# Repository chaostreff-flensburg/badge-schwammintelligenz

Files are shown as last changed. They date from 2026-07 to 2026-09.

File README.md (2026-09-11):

# badge-schwammintelligenz

## Ideensammlung
- PCB mit Gehirn-Form und Schwamm-Farbe
  - gelber Lötstopplack
  - nacktes FR4 als Kontrastfarbe für Porösität des Schwammes
  - Konturlinien in schwarzem oder weißem Bestückungsdruck
- viele sehr kleine LEDs auf der Vorderseite
  - blitzen auf, um Neuronen zu mimen
  - mit [Charlieplexing](https://en.wikipedia.org/wiki/Charlieplexing#Origin) kann man 110 LEDs mit nur 11 Pins einzeln ansteuern
    - (`nLedsMax = nGpio * (nGpio - 1)`)
    - [Beispielcode für Charlieplexing](https://goodarduinocode.com/guides/charlieplexing) -> Zeilenweise ansteuern
  - [XINGLIGHT XL0201UWC](https://jlcpcb.com/partdetail/XINGLIGHT-XL0201UWC/C965789) wäre z.B. nur 0,7 mm * 0,4 mm groß (Pads komplett unter dem Package) und kostet nur 0,0326 USD / St. bei 5000 St. Abnahme
- Kompatibilität zu Mesh-Cat-Ears?
  - [Rudelblinken](https://github.com/zebreus/rudelblinken)
  - Die laufen mit BLE auf einem ESP32-C3
  - Wir könnten denselben Controller nutzen, um mit den Katzenohren meshen zu können
- ein Taster auf der Rückseite, um einen Puls auszulösen
  - erstmal an den eigenen LEDs
  - langfristig sonst auch auf Gehirnen in der Nähe
  - evtl. jeder Mesh-Teilnehmer eine eigene LED?
  - 3-4 Taster (Soft touch) (Typ [Alps SKPM](https://tech.alpsalpine.com/e/products/detail/SKPMANE010/)?)

## Implementierung der Farben

Die Platine wird mit **gelbem Lötstopplack** und **weißem Bestückungsdruck** gefertigt.

Kupfer auf der Rückseite minimal halten und wo möglich unter dem Kupfer der Oberseite verlegen.

Der Entwurf sieht folgendermaßen aus:

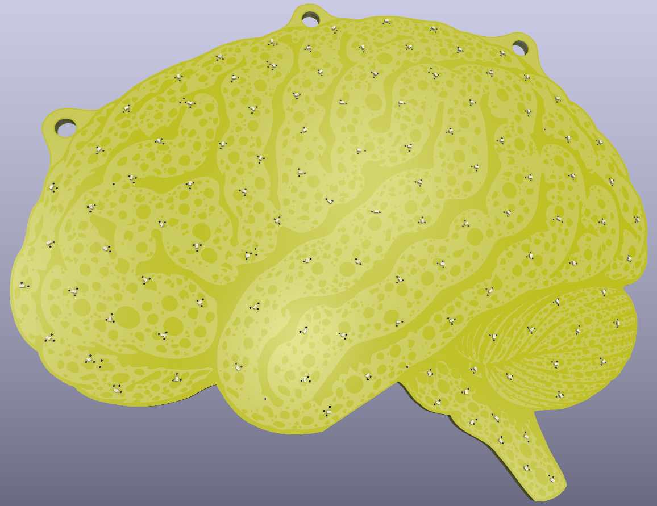
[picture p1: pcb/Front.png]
von vorne


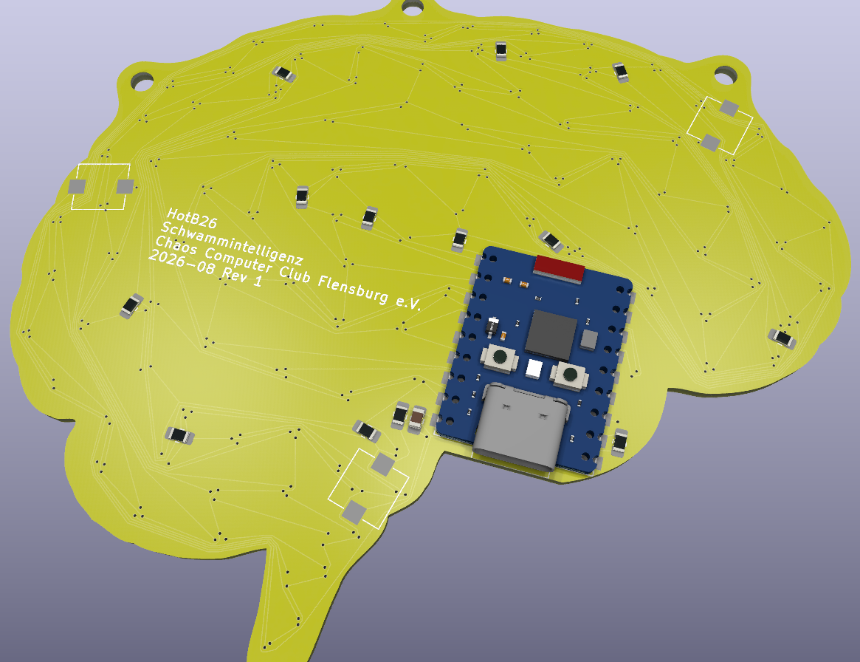
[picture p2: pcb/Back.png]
von hinten


### Farbaufbau

| Farbe | Objekte | Beteiligte Lagen | Notizen |
| --- | --- | --- | --- |
| weiß | ??? | F.Silkscreen | Bestückungsdruck (muss auf Lötstopplack liegen) |
| silber | ??? | F.Cu, F.Mask | freies Kupfer mit HASL Finish |
| hellergelb | Schwammoberfläche | F.Mask | blankes FR4 (kein Kupfer auf der Rückseite) - ca. `e9d645ff` |
| hellgelb | Vertiefung flach | none | Lötstopplack auf FR4 (kein Kupfer auf der Rückseite) - ca. `f6c50eff` |
| dunkelgelb | Vertiefung tief | F.Cu | Lötstopplack auf Kupfer - ca. `e8b203ff` |
| grüngelb | --- | F.Cu, F.Mask | blankes FR4 mit Kupfer auf der Rückseite |

### Lagenaufbau

| Lage | Objekte |
| --- | --- |
| F.Cu | union( silber, dunkelgelb ) |
| F.Mask | invert( union( weiß, hellgelb, dunkelgelb ) ) |
| F.Silkscreen | weiß |

## BOM

Die folgenden Preise beziehen sich auf ein einzelnes Badge wenn wir Material für 50 Stück kaufen.

- JLCPCB Preis vom 2026-06-15
  - PCB ca. 100 mm x 100 mm
  - Silkscreen gleb
  - 1,6 mm dick
  - LeadFree HASL
  - je 110 St. XINGLIGHT XL-0201UWC (LCSC C965789) von JLCPCB auf der Vorderseite bestückt
  - 258,80 € (Material und Produktion) + 48,03 € (Versand EuroPacket) = 306,83 €
  - Es ist mit 2 Wochen Lieferzeit zu rechnen, wenn es keine Rücksprachen braucht

| Anzahl | Preis | Bezeichnung |
| --- | --- | --- |
| 1 | 6,14 € | PCB mit LEDs (Stand 2026-06-15 von JLCPCB teilbestückt) |
| 1 | ca. 4 € | ESP32-C3 |
| ? | ??? | ??? |

## Firmware

Liegt in `firmware/` und läuft auf dem Waveshare ESP32-C3-Zero.

**Für alle, die einfach ein Badge haben:** Auf https://schwammhirn.c3fl.de/ gibt es alles in
einer Seite. Badge per USB anstecken, „Firmware flashen“ klicken, Port wählen. Danach per
Bluetooth verbinden und steuern. Keine Installation nötig, Chrome oder Edge am Desktop reicht
(zum Steuern auch Chrome auf Android, auf dem iPhone der Browser „Bluefy“).

**Zum Mitentwickeln:** Bauen wahlweise mit der Arduino IDE (Board „Waveshare ESP32-C3-Zero“,
Bibliothek NimBLE-Arduino 2.x) oder mit PlatformIO im Repo-Root: `pio run -t upload`.

- `firmware/led_map.h` wird von `tools/gen_led_map.py` aus `pcb/pcb.kicad_pcb` erzeugt
  (Pin-Paar, Position und Hirnareal jeder LED, die Areale aus den Beschriftungen auf
  Cmts.User). Nach Layoutänderungen neu ausführen, das Skript schreibt auch `web/led_map.js`.
- Ein Timer-Interrupt scannt die Charlieplex-Matrix mit 4 Bit Helligkeit, `loop()`
  rendert Animationen in einen Framebuffer.
- Taster: kurz drücken löst eine Welle aus (auch auf Badges in Reichweite), lang drücken
  wechselt den Modus (Neuronen, Wellen, Cortex, Suche, Laufschrift, Löt-Test). Im Löt-Test startet kurz
  drücken den Durchlauf von vorne. Alle drei Taster liegen auf demselben Eingang.
- Sync: Badges senden Modus, Tempo, Helligkeit, Schriftlayout und Phase per BLE-Advertising.
  Die höchste Änderungsgeneration gewinnt, bei Gleichstand die kleinere ID. Kein
  Verbindungsaufbau nötig. Der Text selbst wird nicht übertragen.
- BLE-Anzeigename ist standardmäßig `Schwammhirn-<ID>` aus der Bluetooth-MAC, änderbar.
  Die Web-Seite findet Badges über die Herstellerkennung im Werbepaket, unabhängig vom Namen.

### Modi

| Modus | Kommando | Was passiert |
| --- | --- | --- |
| Neuronen | `mode neurons` | zufällige Blitze, die ausklingen (Standard) |
| Wellen | `mode pulse` | Ringe laufen von einem zufälligen Punkt nach außen |
| Suche | `mode radar` | Radarstrahl kreist um die Mitte. Je Badge in Reichweite ein Herzschlag-Ring von innen nach außen, schneller und heller je näher (Signalstärke der Werbepakete, −95 dBm weit bis −65 dBm direkt daneben) |
| Cortex | `mode cortex` | ein Hirnareal (Frontal-, Parietal-, Temporal-, Okzipitallappen, Kleinhirn, Stammhirn, aus den Beschriftungen im PCB) blitzt auf, schwächere Wellen laufen von dort in den Rest |
| Laufschrift | `mode text` | Text läuft durch, Größe und Abstand oben einstellbar |
| Löt-Test | `mode test` | füllt jede Zeile LED für LED, dann dunkel, nächste Zeile; danach dasselbe spaltenweise. Jede neue LED wird gemeldet. Fehlt eine LED, ist es die Lötstelle; fehlt eine Zeile oder Spalte, der GPIO oder sein 10-Ω-Widerstand. Wird nicht synchronisiert und nicht gespeichert. |
| Malen | `mode remote` | zeigt ein Rohbild, das per `frame` gesendet wurde (Web-Seite: LEDs antippen) |

### Kommandos (Serial und BLE)

Dieselben Textkommandos gehen über Serial (115200 Baud, USB) und über BLE. BLE nutzt den
Nordic-UART-Service (Schreiben auf `6E400002-…`, Antworten als Notify auf `6E400003-…`),
jede BLE-Terminal-App funktioniert also, zum Beispiel „Serial Bluetooth Terminal“ auf Android.
Eine Zeile pro Kommando, Antwort beginnt mit `ok` oder `err`.

| Kommando | Bedeutung |
| --- | --- |
| `mode <name>` oder `mode <0-6>` | Modus wählen: `neurons`, `pulse`, `cortex`, `radar`, `text`, `test`, `remote` |
| `text <Text>` | Laufschrift setzen, max. 63 Zeichen, Umlaute werden ersetzt, schaltet auf Laufschrift |
| `tsize <1-5>` | Schriftgröße (Leinwand-Pixel pro Font-Pixel), Standard 3 |
| `ty <0-30>` | Abstand der Schrift vom oberen Rand, Standard 6 |
| `speed <0-100>` | Tempo aller Animationen, Standard 4 |
| `bright <1-15>` | Helligkeit, Standard 15 |
| `pulse` oder `pulse <LED 0-109>` | Welle auslösen, auch auf Badges in Reichweite. Im Löt-Test: Durchlauf neu starten |
| `frame <220 Hex-Zeichen>` | Rohbild, ein Byte Helligkeit pro LED in D-Reihenfolge, schaltet auf Malen |
| `name <Name>` | BLE-Anzeigename, max. 20 Zeichen, leer = Standard `Schwammhirn-<ID>` |
| `sync on` / `sync off` | Einstellungen von Badges in der Nähe übernehmen oder ignorieren |
| `mirror on` / `mirror off` | Framebuffer etwa 10-mal pro Sekunde als `F<220 Hex>` per BLE-Notify streamen (Live-Bild der Web-Seite) |
| `peers` | Badges in Reichweite mit ID, Signalstärke, Nähe und Alter des letzten Pakets auflisten |
| `status` | Zustand ausgeben: Modus, Tempo, Helligkeit, Schriftlayout, Text, Sync, Generation, ID, Badges in Reichweite, Name |

Modus, Tempo, Helligkeit, Text, Schriftlayout und Name bleiben über Neustarts erhalten.

### Web-Steuerung

Unter https://schwammhirn.c3fl.de/ oder lokal aus `web/index.html`. „Mit Badge verbinden“
drücken, dann Modi, Text, Regler und Umbenennen. Zeigt live das Bild des Badges, im Modus
„Malen“ lassen sich LEDs antippen. Ohne Verbindung läuft dieselbe Animation als Simulation
1:1 auf der Platinenkontur, so lässt sich zum Beispiel Laufschrift vorab beurteilen.
Web Bluetooth braucht HTTPS oder localhost, deshalb funktioniert Verbinden aus dem
Dateisystem nur in Chrome, das `file://` als sicher behandelt.

Firmware flashen ohne Toolchain: Button „Firmware flashen“ (ESP Web Tools, Chrome/Edge am
Desktop). Die Binaries liegen in `web/flash/`, die Seite zeigt den Commit-Hash der Version.
Nach einer Firmware-Änderung: `pio run`, Code committen, dann `tools/export_firmware.sh` und
die Binaries als eigenen Commit nachschieben.

Deployment: Das `Dockerfile` im Repo-Root liefert `web/` per nginx aus. In Coolify eine
Ressource vom Typ „Public Repository“ mit Build Pack „Dockerfile“ anlegen, Port 80, Domain
eintragen. HTTPS macht Coolify per Let's Encrypt. Nach jedem Merge einmal redeployen.

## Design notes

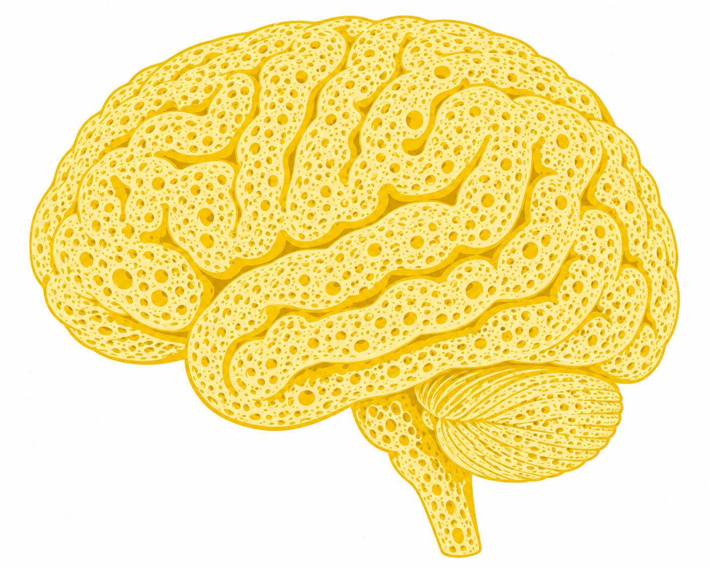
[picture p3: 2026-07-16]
Schwammhirn_original.png

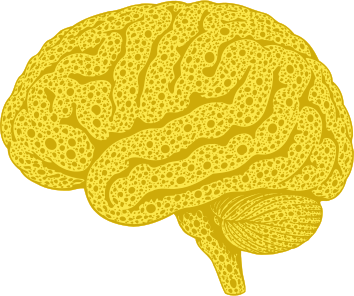
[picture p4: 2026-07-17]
Schwammhirn_3stufig.png

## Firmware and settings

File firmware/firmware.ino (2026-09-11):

// Firmware für das Schwammhirn-Badge: ESP32-C3-Zero auf der Platine aus diesem Repo.
//
// Aufbau:
//   * Ein Timer-Interrupt scannt die 110 Charlieplex-LEDs mit 4 Bit Helligkeit.
//   * loop() rendert Animationen in einen 110-Byte-Framebuffer (0..255 pro LED).
//     Flächige Animationen zeichnen auf eine kleine virtuelle Leinwand, aus der
//     jede LED an ihrer Position auf der Platine abtastet (siehe led_map.h).
//   * Kommandos kommen per Serial oder BLE (Nordic-UART-Service), gleiche Syntax.
//   * Badges in Reichweite synchronisieren Modus, Tempo, Helligkeit und Phase
//     über BLE-Advertising. Ein Tastendruck löst eine Welle auf allen aus.
//
// Kommandos (Serial 115200 oder BLE RX, eine Zeile pro Kommando):
//   mode <0-6|neurons|pulse|cortex|radar|text|test|remote>   Modus wählen
//                      cortex: ein Hirnareal blitzt auf, schwächere Wellen laufen in den Rest
//                      radar: Suchmodus, Radarstrahl kreist, je Badge in Reichweite ein Herzschlag-Ring,
//                             schneller und heller je näher (Signalstärke der Werbepakete)
//                      test: Löt-Test, füllt jede Zeile LED für LED, dann aus, nächste Zeile;
//                      danach dasselbe mit den Spalten. So läuft jeder GPIO als Kathode und Anode.
//   text <Text>        Laufschrift setzen (ASCII, Umlaute werden ersetzt)
//   name <Name>        BLE-Anzeigename (max. 20 Zeichen), Standard Schwammhirn-<ID>
//   tsize <1-5>        Schriftgröße der Laufschrift (Leinwand-Pixel pro Font-Pixel)
//   ty <0-30>          Abstand der Laufschrift vom oberen Rand in Leinwand-Pixeln
//   speed <0-100>      Tempo
//   bright <1-15>      Helligkeit
//   pulse              Welle auslösen (auch auf Badges in Reichweite); im Löt-Test: Test neu starten
//   frame <220 Hex>    Rohbild, ein Byte pro LED, schaltet auf Modus remote
//   sync <on|off>      Sync mit anderen Badges
//   mirror <on|off>    Framebuffer als "F<hex>" per BLE-Notify streamen (~10 Hz)
//   status             Zustand ausgeben
//   peers              Badges in Reichweite mit Signalstärke auflisten

#include <Arduino.h>
#include <NimBLEDevice.h>
#include <Preferences.h>
#include <soc/gpio_reg.h>
#include <driver/gpio.h>
#include <esp_mac.h>
#include <esp_random.h>
#include <math.h>

#include "led_map.h"
#include "font5x7.h"

constexpr int MATRIX_PINS[PIN_COUNT] = {5, 6, 4, 7, 3, 8, 2, 9, 1, 0, 20}; // Col0..Col10
constexpr int BUTTON_PIN = 21; // alle drei Taster parallel, aktiv HIGH

// WS2812-Status-LED des C3-Zero an GPIO10. Bewusst nicht RGB_BUILTIN: die generische
// C3-Variante legt das auf GPIO8, und das ist Zeile 5 der LED-Matrix.
constexpr int STATUS_LED = SOC_GPIO_PIN_COUNT + 10;

// Typen stehen vor der ersten Funktion, weil der Arduino-Präprozessor dort seine Prototypen einfügt.
enum Mode : uint8_t { NEURONS, PULSE, CORTEX, RADAR, TEXT, TEST, REMOTE, MODE_COUNT }; // Taster rotiert bis TEST; ab TEST kein Sync, kein Speichern

struct __attribute__((packed)) SyncPacket
{
  uint8_t company[2]; // 0xFFFF = Testkennung
  uint8_t magic[2];   // 'S','H'
  uint8_t version;
  uint16_t id;
  uint16_t generation;
  uint8_t mode, speed, brightness;
  uint16_t phase;     // animTime() & 0xFFFF
  uint8_t pulseSeq, pulseOrigin;
  uint8_t textScale, textY;
};

// Badges in Reichweite, gesehen über ihre Sync-Pakete
struct Peer { uint16_t id; uint8_t pulseSeq; uint32_t lastSeen; int8_t rssi; };
Peer peers[16];
constexpr uint32_t PEER_TIMEOUT_MS = 10000;
inline bool peerActive(const Peer& p) { return p.id && millis() - p.lastSeen < PEER_TIMEOUT_MS; }
// Nähe 0..1 aus der Signalstärke. Gemessen: nebeneinander auf dem Tisch -75 dBm, anderer Raum -97 dBm.
float peerNearness(const Peer& p) { return constrain((p.rssi + 95) / 30.0f, 0.0f, 1.0f); }

constexpr bool pinInMatrix(int gpio)
{
  for (int p : MATRIX_PINS)
    if (p == gpio) return true;
  return false;
}
static_assert(!pinInMatrix(STATUS_LED - SOC_GPIO_PIN_COUNT), "Status-LED liegt auf einem Matrix-Pin");
static_assert(!pinInMatrix(BUTTON_PIN), "Taster liegt auf einem Matrix-Pin");

// ---------------------------------------------------------------------------
// Charlieplex-Scan (Timer-ISR). 4 Bitebenen pro Spalte, Bitebene b dauert 2^b Ticks.
// ---------------------------------------------------------------------------
constexpr int PLANES = 4;
constexpr uint32_t TICK_US = 30; // 11 Spalten * 15 Ticks * 30 us = 5 ms => ~200 Hz Bildwiederholung

uint32_t pinMask[PIN_COUNT];
uint32_t allPinsMask = 0;
volatile uint32_t rowMask[2][PIN_COUNT][PLANES]; // [Puffer][Spalte][Bitebene] -> Kathoden-Pins
volatile uint8_t activeBuf = 0;
hw_timer_t* scanTimer = nullptr;

void ARDUINO_ISR_ATTR onScanTick()
{
  static uint8_t col = 0, plane = 0, remaining = 1;
  if (--remaining) return;

  REG_WRITE(GPIO_ENABLE_W1TC_REG, allPinsMask); // alles hochohmig
  uint32_t rows = rowMask[activeBuf][col][plane];
  if (rows)
  {
    REG_WRITE(GPIO_OUT_W1TS_REG, pinMask[col]);
    REG_WRITE(GPIO_OUT_W1TC_REG, rows);
    REG_WRITE(GPIO_ENABLE_W1TS_REG, pinMask[col] | rows);
  }

  remaining = 1 << plane;
  if (++plane == PLANES)
  {
    plane = 0;
    if (++col == PIN_COUNT) col = 0;
  }
}

// ---------------------------------------------------------------------------
// Zustand
// ---------------------------------------------------------------------------
const char* const MODE_NAMES[MODE_COUNT] = {"neurons", "pulse", "cortex", "radar", "text", "test", "remote"};

struct State
{
  Mode mode = NEURONS;
  uint8_t speed = 4;      // 0..100
  uint8_t brightness = 15; // 1..15
  char text[64] = "SCHWAMMHIRN";
  char name[21] = "";     // BLE-Anzeigename, leer = Standard aus myId
  uint8_t textScale = 3;  // 1..5
  uint8_t textY = 6;      // 0..30
  bool syncEnabled = true;
  bool mirror = false;
} st;

uint8_t fb[LED_COUNT];      // Framebuffer 0..255
uint32_t epoch = 0;         // Animationszeit t = millis() - epoch, per Sync verschiebbar
uint16_t generation = 0;    // Lamport-Zähler für den Sync: höchste Generation gewinnt
uint16_t myId;
uint8_t pulseSeq = 0;       // zählt eigene Pulse, damit Nachbarn neue erkennen
uint8_t pulseOrigin = 0;
uint32_t dirtySince = 0;    // Zeitpunkt der letzten Änderung, für verzögertes Speichern
bool advertDirty = true;

Preferences prefs;

inline uint32_t animTime() { return millis() - epoch; }

// ---------------------------------------------------------------------------
// Framebuffer -> Scan-Puffer
// ---------------------------------------------------------------------------
void show()
{
  uint8_t next = activeBuf ^ 1;
  for (int c = 0; c < PIN_COUNT; ++c)
    for (int p = 0; p < PLANES; ++p) rowMask[next][c][p] = 0;

  for (int i = 0; i < LED_COUNT; ++i)
  {
    uint8_t v = (fb[i] * (st.brightness + 1)) >> 8; // 0..brightness
    for (int p = 0; p < PLANES; ++p)
      if (v & (1 << p)) rowMask[next][LEDS[i].col][p] |= pinMask[LEDS[i].row];
  }
  activeBuf = next;
}

// ---------------------------------------------------------------------------
// Virtuelle Leinwand, ca. 2 mm pro Pixel
// ---------------------------------------------------------------------------
constexpr int CW = 48;
constexpr int CH = 40;
uint8_t canvas[CW * CH];

void canvasClear() { memset(canvas, 0, sizeof(canvas)); }

inline void canvasSet(int x, int y, uint8_t v)
{
  if (x < 0 || y < 0 || x >= CW || y >= CH) return;
  uint8_t& px = canvas[y * CW + x];
  if (v > px) px = v;
}


// Jede LED nimmt das Maximum ihrer Nachbarschaft (radius 1 = 3x3), damit dünne Linien nicht durchfallen.
void sampleCanvas(int radius)
{
  for (int i = 0; i < LED_COUNT; ++i)
  {
    int cx = LEDS[i].x * CW / 256, cy = LEDS[i].y * CH / 256;
    uint8_t m = 0;
    for (int dy = -radius; dy <= radius; ++dy)
      for (int dx = -radius; dx <= radius; ++dx)
      {
        int x = cx + dx, y = cy + dy;
        if (x >= 0 && y >= 0 && x < CW && y < CH) m = max(m, canvas[y * CW + x]);
      }
    fb[i] = m;
  }
}

// ---------------------------------------------------------------------------
// Wellen (Overlay in jedem Modus)
// ---------------------------------------------------------------------------
struct Wave { uint32_t start; uint8_t origin; bool active; };
Wave waves[4];

void triggerWave(uint8_t origin)
{
  for (Wave& w : waves)
    if (!w.active)
    {
      w = {millis(), origin, true};
      return;
    }
  waves[0] = {millis(), origin, true};
}

void renderWaves()
{
  for (Wave& w : waves)
  {
    if (!w.active) continue;
    uint32_t age = millis() - w.start;
    if (age > 1800) { w.active = false; continue; }
    float r = age * 0.25f;                     // Radius in LED-Koordinaten (0..255), ~1 Sekunde bis zum Rand
    float fade = 1.0f - age / 1800.0f;
    int ox = LEDS[w.origin].x, oy = LEDS[w.origin].y;
    for (int i = 0; i < LED_COUNT; ++i)
    {
      float d = hypotf(LEDS[i].x - ox, LEDS[i].y - oy);
      float k = 1.0f - fabsf(d - r) / 30.0f;   // Ringbreite 30
      if (k <= 0) continue;
      uint8_t v = (uint8_t)(255 * k * fade);
      if (v > fb[i]) fb[i] = v;
    }
  }
}

// ---------------------------------------------------------------------------
// Animationen
// ---------------------------------------------------------------------------
void renderNeurons(uint32_t dt)
{
  uint8_t decay = 2 + dt / 4;
  for (int i = 0; i < LED_COUNT; ++i) fb[i] = fb[i] > decay ? fb[i] - decay : 0;
  int flashes = 1 + st.speed / 25;
  for (int n = 0; n < flashes; ++n)
    if (random(100) < 20 + st.speed / 2) fb[random(LED_COUNT)] = 255;
}

// Cortex: ein Hirnareal (siehe AREAS in led_map.h) blitzt flackernd auf, vom Mittelpunkt läuft
// eine schwächere Welle durch die übrigen Areale.
void renderCortex(uint32_t dt)
{
  static uint32_t nextAt = 0, flashAt = 0;
  static int area = -1;
  uint8_t decay = 1 + dt / 8;
  for (int i = 0; i < LED_COUNT; ++i) fb[i] = fb[i] > decay ? fb[i] - decay : 0;
  uint32_t now = millis();
  if (now >= nextAt)
  {
    int next;
    do next = random(AREA_COUNT); while (next == area && AREA_COUNT > 1);
    area = next;
    flashAt = now;
    nextAt = now + 2600 - st.speed * 20;
  }
  uint32_t age = now - flashAt;
  if (age < 450)
    for (int i = 0; i < LED_COUNT; ++i)
      if (LEDS[i].area == area && random(2) == 0) fb[i] = 255;
  float r = ((int32_t)age - 200) * 0.2f;
  if (r > 0 && age < 2000)
  {
    float fade = 0.4f * (1.0f - age / 2000.0f);
    int ax = AREAS[area].x, ay = AREAS[area].y;
    for (int i = 0; i < LED_COUNT; ++i)
    {
      if (LEDS[i].area == area) continue;
      float k = 1.0f - fabsf(hypotf(LEDS[i].x - ax, LEDS[i].y - ay) - r) / 25.0f;
      if (k <= 0) continue;
      uint8_t v = (uint8_t)(255 * k * fade);
      if (v > fb[i]) fb[i] = v;
    }
  }
}

// Suche: Radarstrahl kreist um die Mitte, je Badge in Reichweite ein Herzschlag-Ring von innen
// nach außen, schneller und heller je näher. Gleiche Parameter wie die Web-Simulation.
void renderRadar(uint32_t t, uint32_t dt)
{
  constexpr int CX = 132, CY = 118;
  static float angle[LED_COUNT], dist[LED_COUNT];
  static bool prepared = false;
  if (!prepared)
  {
    for (int i = 0; i < LED_COUNT; ++i)
    {
      angle[i] = atan2f(LEDS[i].y - CY, LEDS[i].x - CX);
      dist[i] = hypotf(LEDS[i].x - CX, LEDS[i].y - CY);
    }
    prepared = true;
  }
  uint8_t decay = 3 + dt / 4;
  for (int i = 0; i < LED_COUNT; ++i) fb[i] = fb[i] > decay ? fb[i] - decay : 0;

  int nodes = 0;
  float maxNear = 0;
  for (Peer& p : peers)
    if (peerActive(p))
    {
      ++nodes;
      maxNear = max(maxNear, peerNearness(p));
    }

  float sweep = fmodf(t * (0.0012f + maxNear * 0.0025f), 2 * PI) - PI;
  for (int i = 0; i < LED_COUNT; ++i)
  {
    float d = fabsf(angle[i] - sweep);
    if (d > PI) d = 2 * PI - d;
    float k = 1.0f - d / 0.35f;
    if (k > 0) fb[i] = max(fb[i], (uint8_t)(90 * k));
  }

  int n = 0;
  for (Peer& p : peers)
  {
    if (!peerActive(p)) continue;
    float near = peerNearness(p);
    uint32_t period = 2200 - near * 1700;
    float amp = 0.35f + 0.65f * near;
    uint32_t age = (t + n++ * period / nodes) % period;
    if (age > period * 0.8f) continue;
    float r = age * 0.28f;
    for (int i = 0; i < LED_COUNT; ++i)
    {
      float k = 1.0f - fabsf(dist[i] - r) / 22.0f;
      if (k <= 0) continue;
      uint8_t v = (uint8_t)(255 * k * amp * (1.0f - (float)age / period));
      if (v > fb[i]) fb[i] = v;
    }
  }
}

void renderPulseMode(uint32_t t)
{
  static uint32_t nextAt = 0;
  memset(fb, 0, sizeof(fb));
  if (millis() >= nextAt)
  {
    // ponytail: Ursprung aus t abgeleitet, damit synchronisierte Badges denselben wählen
    triggerWave((t / 100) % LED_COUNT);
    nextAt = millis() + 2500 - st.speed * 20;
  }
}


void renderText(uint32_t t)
{
  canvasClear();
  const int SCALE = st.textScale, GAP = SCALE, ADV = FONT_W * SCALE + GAP;
  int n = strlen(st.text);
  if (n == 0) { sampleCanvas(0); return; }
  int total = n * ADV + CW;
  int offset = (int)((t * (10 + st.speed) / 400) % total);
  int y0 = st.textY;
  for (int ci = 0; ci < n; ++ci)
  {
    int x0 = CW + ci * ADV - offset;
    if (x0 + FONT_W * SCALE < 0 || x0 >= CW) continue;
    uint8_t ch = st.text[ci];
    if (ch < FONT_FIRST || ch > FONT_LAST) ch = '?';
    const uint8_t* glyph = FONT5X7[ch - FONT_FIRST];
    for (int gx = 0; gx < FONT_W; ++gx)
      for (int gy = 0; gy < FONT_H; ++gy)
        if (glyph[gx] & (1 << gy))
          for (int dx = 0; dx < SCALE; ++dx)
            for (int dy = 0; dy < SCALE; ++dy) canvasSet(x0 + gx * SCALE + dx, y0 + gy * SCALE + dy, 255);
  }
  sampleCanvas(SCALE >= 3 ? 0 : 1); // breite Striche ohne Nachbarschaft, sonst bleiben Buchstaben Blobs
}

// Löt-Test: Gruppe 0..10 = Zeilen, 11..21 = Spalten. Je Gruppe 10 Schritte zum Auffüllen,
// dann ein Schritt dunkel. Meldet jede neu hinzukommende LED.
int testLast = -1; // -1 = Test nicht aktiv, sonst zuletzt gemeldeter Schritt
constexpr int TEST_GROUPS = 2 * PIN_COUNT, TEST_STEPS = PIN_COUNT; // 10 LEDs + 1 Pause
void renderTest()
{
  static uint32_t startedAt = 0;
  if (testLast < 0) startedAt = millis();
  uint32_t stepMs = 150 - st.speed; // 146 ms bei Tempo 4, 50 ms bei Tempo 100
  int step = ((millis() - startedAt) / stepMs) % (TEST_GROUPS * TEST_STEPS);
  int group = step / TEST_STEPS, k = step % TEST_STEPS;
  bool byRow = group < PIN_COUNT;
  int pin = byRow ? group : group - PIN_COUNT;
  memset(fb, 0, sizeof(fb));
  int added = -1;
  if (k < TEST_STEPS - 1)
  {
    int n = 0;
    for (int other = 0; other < PIN_COUNT && n <= k; ++other) // Partner-Pins aufsteigend
      for (int i = 0; i < LED_COUNT; ++i)
        if ((byRow ? LEDS[i].row == pin && LEDS[i].col == other : LEDS[i].col == pin && LEDS[i].row == other))
        {
          fb[i] = 255;
          if (n == k) added = i;
          ++n;
        }
  }
  if (step != testLast)
  {
    testLast = step;
    String where = String(byRow ? "row" : "col") + pin + " (GPIO" + MATRIX_PINS[pin] + (byRow ? " low)" : " high)");
    if (added < 0) reply("test " + where + " fertig");
    else reply("test " + where + " +D" + (added + 1) + " " + (byRow ? "col" : "row") + (byRow ? LEDS[added].col : LEDS[added].row));
  }
}

void renderFrame()
{
  static uint32_t last = 0;
  uint32_t now = millis(), dt = now - last;
  last = now;
  uint32_t t = animTime();
  switch (st.mode)
  {
    case NEURONS: renderNeurons(dt); break;
    case PULSE: renderPulseMode(t); break;
    case CORTEX: renderCortex(dt); break;
    case RADAR: renderRadar(t, dt); break;
    case TEXT: renderText(t); break;
    case REMOTE: break; // fb kommt per "frame"-Kommando
    case TEST: renderTest(); break;
    default: break;
  }
  if (st.mode != TEST) testLast = -1;
  if (st.mode != TEST) renderWaves();
  show();
}

// ---------------------------------------------------------------------------
// Sync über BLE-Advertising (Manufacturer Data)
// ---------------------------------------------------------------------------


NimBLECharacteristic* txChar = nullptr;
NimBLEAdvertising* adv = nullptr;

void bumpGeneration() { ++generation; advertDirty = true; }

void markDirty()
{
  dirtySince = millis();
  bumpGeneration();
}

void updateAdvert()
{
  SyncPacket p = {{0xFF, 0xFF}, {'S', 'H'}, 1, myId, generation, st.mode, st.speed, st.brightness,
                  (uint16_t)animTime(), pulseSeq, pulseOrigin, st.textScale, st.textY};
  adv->setManufacturerData((const uint8_t*)&p, sizeof(p));
  if (adv->isAdvertising()) adv->refreshAdvertisingData();
  advertDirty = false;
}


int peerCount()
{
  int n = 0;
  for (Peer& p : peers) if (peerActive(p)) ++n;
  return n;
}



void onSyncPacket(const SyncPacket& p, int rssi)
{
  Peer* peer = nullptr;
  Peer* slot = nullptr;
  for (Peer& q : peers)
  {
    if (q.id == p.id) peer = &q;
    if (!slot && (q.id == 0 || millis() - q.lastSeen > 10000)) slot = &q;
  }
  bool known = peer != nullptr;
  if (!peer) peer = slot ? slot : &peers[0];
  if (known && peer->pulseSeq != p.pulseSeq) triggerWave(p.pulseOrigin < LED_COUNT ? p.pulseOrigin : 0);
  int8_t smoothed = known && peerActive(*peer) ? (peer->rssi * 3 + rssi) / 4 : rssi; // RSSI schwankt stark
  *peer = {p.id, p.pulseSeq, millis(), smoothed};

  if (!st.syncEnabled || p.mode >= TEST || st.mode >= TEST) return;
  bool newer = p.generation > generation || (p.generation == generation && p.id < myId);
  if (!newer) return;
  int16_t drift = (int16_t)(p.phase - (uint16_t)animTime());
  if (abs(drift) > 40) epoch -= drift;
  if (p.generation != generation || p.mode != st.mode || p.speed != st.speed || p.brightness != st.brightness ||
      p.textScale != st.textScale || p.textY != st.textY)
  {
    generation = p.generation;
    st.mode = (Mode)min<uint8_t>(p.mode, TEXT);
    st.speed = min<uint8_t>(p.speed, 100);
    st.brightness = constrain(p.brightness, 1, 15);
    st.textScale = constrain(p.textScale, 1, 5);
    st.textY = min<uint8_t>(p.textY, 30);
    dirtySince = millis();
    advertDirty = true;
  }
}

class ScanCallbacks : public NimBLEScanCallbacks
{
  void onResult(const NimBLEAdvertisedDevice* dev) override
  {
    if (!dev->haveManufacturerData()) return;
    std::string d = dev->getManufacturerData();
    if (d.size() != sizeof(SyncPacket)) return;
    SyncPacket p;
    memcpy(&p, d.data(), sizeof(p));
    if (p.company[0] != 0xFF || p.company[1] != 0xFF || p.magic[0] != 'S' || p.magic[1] != 'H' || p.id == myId) return;
    onSyncPacket(p, dev->getRSSI());
  }
} scanCallbacks;

// ---------------------------------------------------------------------------
// Kommandos
// ---------------------------------------------------------------------------
void reply(const String& s)
{
  Serial.println(s);
  if (txChar && NimBLEDevice::getServer()->getConnectedCount()) txChar->notify((const uint8_t*)s.c_str(), s.length());
}

void setMode(Mode m)
{
  st.mode = m;
  markDirty();
}

void applyName() // nach setupBle() aufrufen
{
  if (!st.name[0]) snprintf(st.name, sizeof(st.name), "Schwammhirn-%04X", myId);
  NimBLEDevice::setDeviceName(st.name);
  adv->setName(st.name);
  if (adv->isAdvertising()) adv->refreshAdvertisingData();
}

void setText(const char* src)
{
  // UTF-8-Umlaute auf ASCII abbilden, Kleinbuchstaben hochsetzen
  int o = 0;
  for (const uint8_t* s = (const uint8_t*)src; *s && o < (int)sizeof(st.text) - 1; ++s)
  {
    uint8_t c = *s;
    if (c == 0xC3 && s[1])
    {
      uint8_t u = *++s;
      c = (u == 0x84 || u == 0xA4) ? 'A' : (u == 0x96 || u == 0xB6) ? 'O' : (u == 0x9C || u == 0xBC) ? 'U' : (u == 0x9F) ? 'S' : '?';
      if (u == 0x9F && o < (int)sizeof(st.text) - 2) st.text[o++] = 'S';
    }
    else if (c >= 0x80) c = '?';
    st.text[o++] = toupper(c);
  }
  st.text[o] = 0;
}

int hexVal(char c)
{
  if (c >= '0' && c <= '9') return c - '0';
  c = tolower(c);
  if (c >= 'a' && c <= 'f') return c - 'a' + 10;
  return -1;
}
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
void loop()
{
  static String serialLine;
  while (Serial.available())
  {
    char c = Serial.read();
    if (c == '\n' || c == '\r')
    {
      handleCommand(serialLine);
      serialLine = "";
    }
    else if (serialLine.length() < 300) serialLine += c;
  }

  handleButton();
  renderFrame();
  sendMirror();
  saveSettingsIfDue();

  static uint32_t lastAdvert = 0;
  if (advertDirty || millis() - lastAdvert > 500)
  {
    lastAdvert = millis();
    updateAdvert();
  }
  delay(16);
}

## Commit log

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2026-06-14 added placeholder pcb to check for prices circular pcb with 100 mm diameter and 110 XINGLIGHT XL-0201UWC LEDs on the top side but without any connections
    [pcb.kicad_pcb, pcb.kicad_sch]
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2026-07-15 added planning tables for how to make the different colors on the PCB design
2026-07-16 Added svg files for sponge brain and imported to PCB
    [pcb.kicad_pcb, pcb.kicad_sch]
2026-07-17 inverted brain svg so that it can become zone exclude area in KiCAD
2026-07-17 finished charlieplexinc circuits in schematic, imported inverted svg, marked brain regions and distributed LEDs to the regions
    [pcb.kicad_sch]
2026-07-17 added vias to all LEDs and distributed Col0 LEDs into frontal cortex
2026-07-17 added JLC part number for series resistors and fixed clearance issues
2026-07-17 distributed LEDs of frontal cortex and did some experimental wiring for them
    [pcb.kicad_pcb]
2026-07-18 distributed LEDs of parietal lobe (Col3, Col4)
    [pcb.kicad_pcb]
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2026-07-19 added ESP32-C3-Zero module and push buttons to schematic
    [pcb.kicad_sch]
2026-07-19 added attachement points for necklace and worked on LED placement and wiring drafted concept for organizing the matrix wiring added buttons and ESP32 module to PCB started laying out the LED position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
    [pcb.kicad_pcb]
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2026-07-19 added third keychain hole at the top center
    [pcb.kicad_pcb]
2026-07-19 sorted some lines
    [pcb.kicad_pcb]
2026-07-30 increased minimum via dimensions to match cheapest JLCPCB capability tier (0.3/0.45)
    [pcb.kicad_pcb]
2026-07-30 placed and distributed all LED position markers
    [pcb.kicad_pcb]
2026-07-30 linked up Row3 in planning layers
    [pcb.kicad_pcb]
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2026-08-11 placed and routed LED R0C3
    [pcb.kicad_pcb]
2026-08-13 placed remaining parts of row 0 and 1
    [pcb.kicad_pcb]
2026-08-13 placed row 3 and 4
    [pcb.kicad_pcb]
2026-08-13 placed row 5 and 6
    [pcb.kicad_pcb]
2026-08-13 placed remaining LEDs and resistors
    [pcb.kicad_pcb]
2026-08-14 routed Row0
    [pcb.kicad_pcb]
2026-08-18 routed some connections
    [pcb.kicad_pcb]
2026-08-18 moved Column planning lines to separate layers per column for better overview
    [pcb.kicad_pcb]
2026-08-18 routed Col0 with curves
    [pcb.kicad_pcb]
2026-08-18 routed Row1, Row4 and Col10
    [pcb.kicad_pcb]
2026-08-18 deleted obsolete tracks
    [pcb.kicad_pcb]
2026-08-18 routed Row2, Row3 and Row5
    [pcb.kicad_pcb]
2026-08-18 routed row10
    [pcb.kicad_pcb]
2026-08-19 routed rest of the rows and some cols
    [pcb.kicad_pcb]
2026-08-19 wildly routed a lot more
    [pcb.kicad_pcb]
2026-08-21 added name to last unnamed node
    [pcb.kicad_sch]
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2026-08-21 fixed some minor details
    [pcb.kicad_sch]
2026-08-21 changed C1 to 1uF instead of 100nF for longer debounce time
    [pcb.kicad_sch]
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2026-09-09 added rudimentary first firmware (that hopefully actually works) tested on a bare ESP32-C3-Zero dev board without the actual brain PCB around it
2026-09-11 LED-Karte aus dem KiCad-PCB generieren, PlatformIO-Projekt anlegen
    tools/gen_led_map.py liest pcb/pcb.kicad_pcb und erzeugt firmware/led_map.h
    (Pin-Paar und Position jeder der 110 LEDs) sowie web/led_map.js (Positionen,
    Platinenkontur, Bohrungen, Zeichensatz). Die Anoden/Kathoden-Zuordnung wurde
    gegen den Schaltplan geprüft: Col_i und Row_i teilen sich einen GPIO, LED
    leuchtet bei Col HIGH und Row LOW.
    platformio.ini baut den bestehenden Sketch mit der pioarduino-Plattform
    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
2026-09-11 Firmware: Framebuffer, Animationen, BLE-Steuerung und Badge-Sync
    Behebt zwei Fehler der ersten Version: sizeof(matrixPins) lieferte 44 statt
    11 und ließ alle Schleifen über das Array hinauslaufen; LED_BUILTIN ist auf
    dem C3-Zero eine WS2812, digitalWrite bewirkte dort nichts.
    Neu:
    - Timer-Interrupt scannt die Charlieplex-Matrix mit 4 Bit Helligkeit
    (Bit-Angle-Modulation, ~200 Hz), loop() rendert in einen 110-Byte-Framebuffer.
    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
2026-09-11 Web-Steuerung mit 1:1-Simulation der Platine
    web/index.html verbindet sich per Web Bluetooth mit dem Badge, schaltet Modi,
    setzt Laufschrift, Tempo, Helligkeit, Schriftgröße und Offset und zeigt das
    Live-Bild des Badges. Im Modus "Malen" lassen sich LEDs antippen. Ohne
    Verbindung läuft dieselbe Animation als Simulation auf der Platinenkontur aus
    led_map.js. Eine Datei, kein Build, funktioniert aus dem Dateisystem.
    README um Firmware- und Web-Abschnitt ergänzt.
    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
2026-09-11 Dockerfile für das Hosting der Web-Steuerung
    nginx:alpine liefert web/ aus. Gedacht für Coolify unter schwammhirn.c3fl.de,
    Web Bluetooth verlangt HTTPS.
    Claude-Session: https://claude.ai/code/session_01LnFpW9J7QKbkfiuNSQp2LH
2026-09-11 Firmware im Browser flashen (ESP Web Tools)
    web/flash/ enthält Bootloader, Partitionstabelle, boot_app0 und die Firmware
    des letzten Builds plus Manifest mit den Flash-Offsets des ESP32-C3. Die
    Web-Seite bekommt einen Button „Firmware flashen“ über ESP Web Tools, damit
    niemand Toolchains installieren muss (Chrome/Edge am Desktop, HTTPS).
    tools/export_firmware.sh sammelt die Binaries nach `pio run` neu ein und
    schreibt die Version aus git describe ins Manifest.
    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
2026-09-11 Web-Seite: Bedienelemente je Modus, Mobil-Layout
    Vorschau direkt unter den Modus-Buttons. Text-Eingabe, Schriftgröße und
    Abstand nur bei Laufschrift, Tempo nicht beim Malen. Puls-Button heißt im
    Löt-Test „Test neu starten“. Sync und Anzeigename in einem aufklappbaren
    Abschnitt „Badge-Einstellungen“, Log-Karte erst sichtbar, wenn etwas drinsteht.
    Mobil: Tap-Flächen mindestens 44 px, Modus-Buttons als Raster, Regler in
    voller Breite mit Beschriftung und Wert darüber. [hidden] setzt sich jetzt
    gegen display:flex durch.
    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
